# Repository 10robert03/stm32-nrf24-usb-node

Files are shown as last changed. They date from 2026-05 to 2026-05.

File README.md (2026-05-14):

# STM32-nRF24 Wireless USB Node

A compact 2-layer PCB featuring an **STM32C011** microcontroller and an **nRF24L01+** 2.4GHz wireless transceiver. This project was designed to bridge the gap between custom wireless sensor networks and USB-enabled host systems.

**⚠️ Project Status:** This project is currently in the **Hardware Prototype** stage. The PCB layout is complete, but the board has not yet been fully assembled or laboratory tested. Use with caution for production environments.

## Technical Highlights
- **Microcontroller:** STM32C011 (Arm Cortex-M0+), chosen for its efficiency and compact form factor.
- **Wireless Interface:** nRF24L01+ module connector, providing low-power 2.4GHz communication via SPI.
- **USB-UART Bridge:** Integrated **MCP2200** for seamless serial debugging and data acquisition.
- **Power Management:** Supports wide input voltage (5V - 36V) via **TSR 0.5-2433** DC/DC buck regulator.
  - Reverse polarity protection via Schottky diode.
  - Decoupled USB-C port (Data only) to prevent VBUS conflicts with host devices.

## Engineering Lessons & Design Choices

During the development of this board, several critical hardware engineering principles were implemented to ensure stability and signal integrity:

### 1. High-Frequency Signal Integrity
* **Series Termination:** Integrated series resistors on high-speed lines to dampen ringing and control rise/fall times. This minimizes electromagnetic interference (EMI) and prevents signal reflections.
* **Impedance Control:** Careful routing of USB D+/D- differential pairs to maintain signal quality for the MCP2200 bridge.

### 2. Clock & Timing Precision
* **Independent Oscillators:** Implemented separate external crystals for the STM32 (8 MHz) and MCP2200 (12 MHz). 
* **Parasitic Optimization:** Load capacitors were placed in immediate proximity to the crystals to minimize parasitic inductance and ensure a stable startup of the oscillation.

### 3. Power Integrity & Noise Suppression
* **Decoupling Strategy:** Strategic placement of ceramic decoupling capacitors (100nF) directly at the VCC pins of each IC to provide local energy storage and filter high-frequency switching noise.
* **RF-Sensitive Filtering:** Added LC-filtering stages at the output of the switching regulator to provide a "clean" 3.3V rail for the nRF24L01+, which is highly sensitive to power supply ripple.

### 4. Advanced PCB Layout Techniques
* **Tight Component Placement:** Mastered the challenge of placing high-pin-count components (USB-C, STM32, MCP2200) in a very confined space while maintaining minimum clearance for the Ground Plane (GND).
* **Thermal Management:** Solid Ground Fill on the bottom layer acts as a heat sink and provides a low-impedance return path for all signals.

##  Project Structure
- `/Screenshots`: High-resolution renders, schematic snips, and hardware photos.
- `stm32c_nrf.kicad_pcb`: The 2-layer board layout.
- `stm32c_nrf.kicad_sch`: The full electrical schematic.

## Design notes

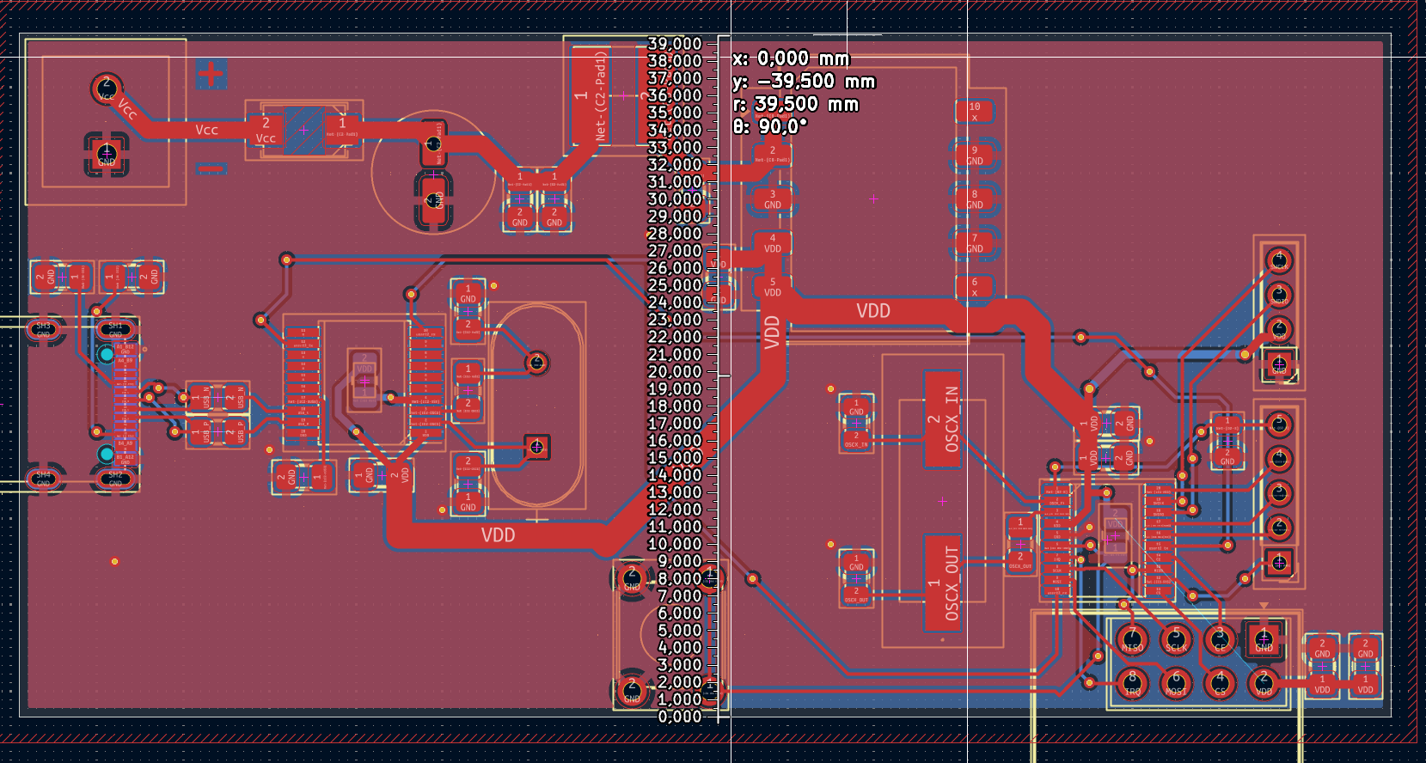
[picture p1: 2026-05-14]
Screenshots/pcb_y_axis_length.png

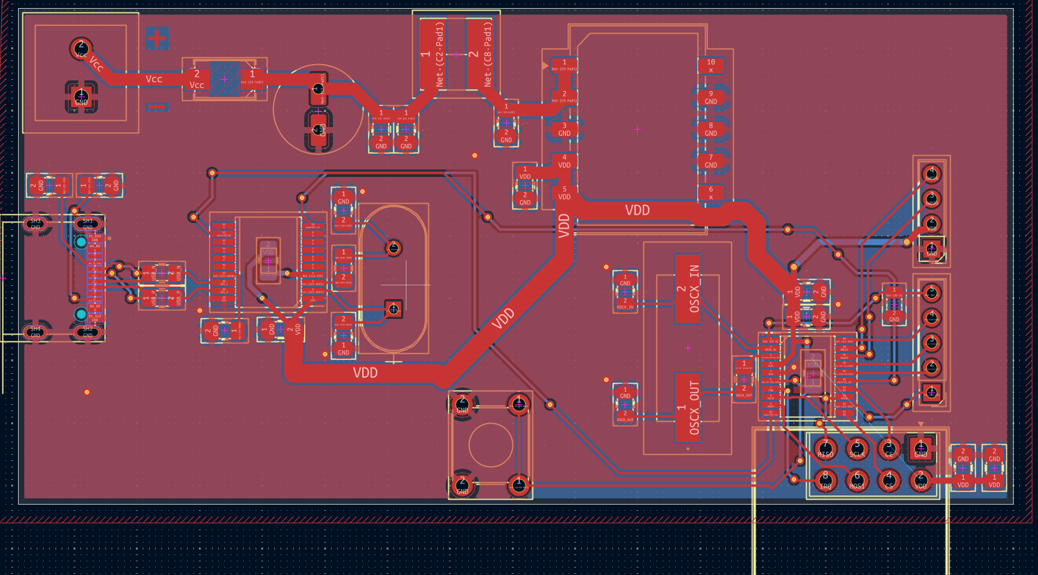
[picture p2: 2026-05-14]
Screenshots/PCB.png

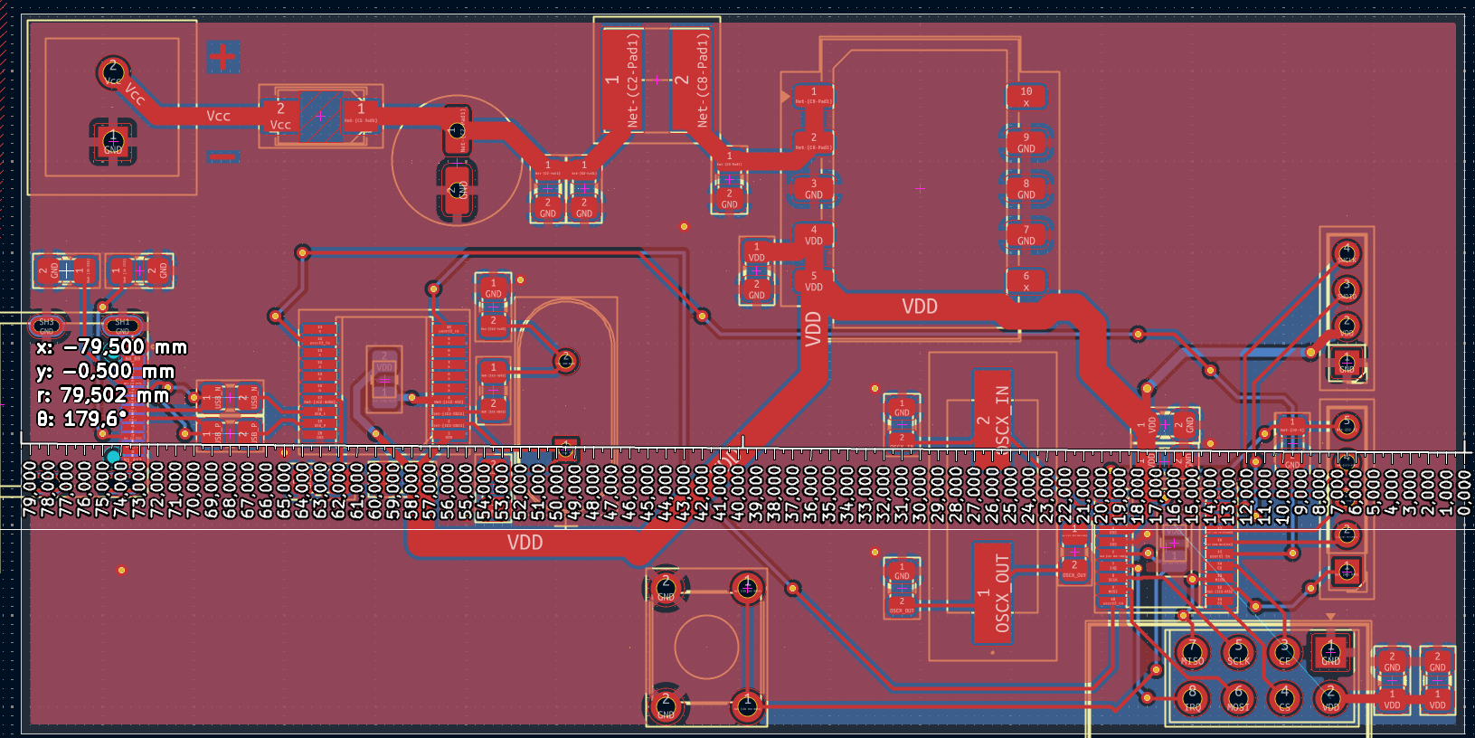
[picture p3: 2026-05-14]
Screenshots/pcb_x_axis_length.png

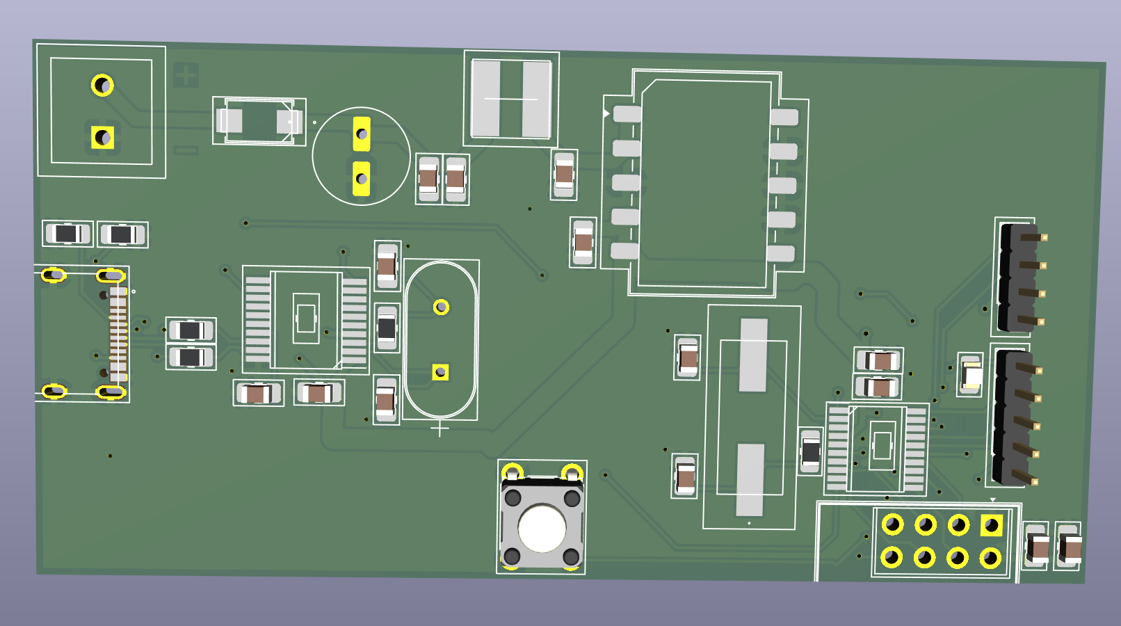
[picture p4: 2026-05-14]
Screenshots/3D_pcb_front.png

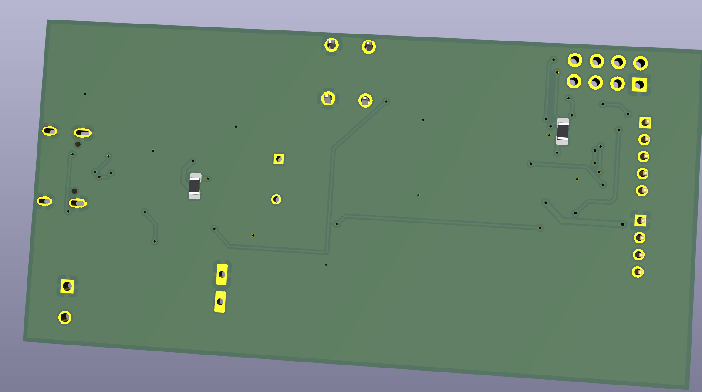
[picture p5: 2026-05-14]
Screenshots/3D_pcb_back.png

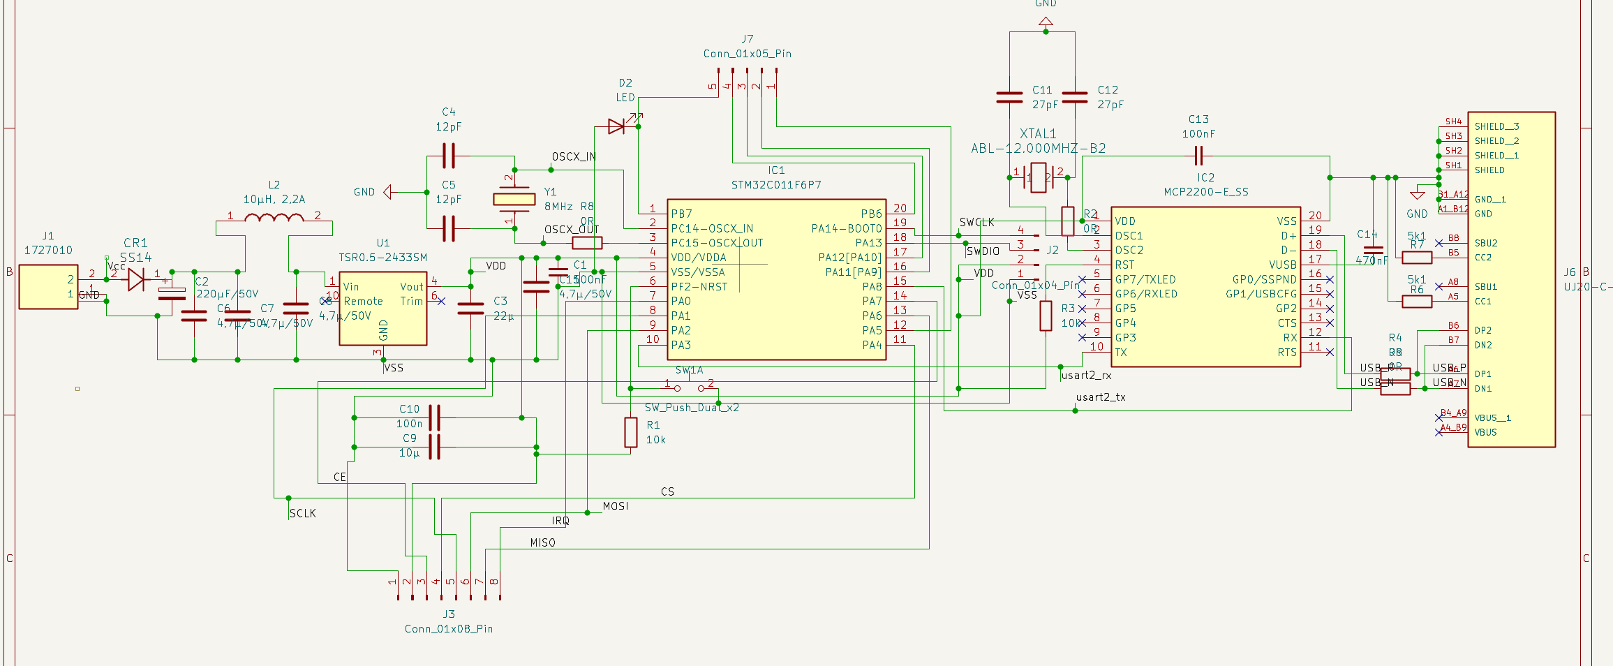
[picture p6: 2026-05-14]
Screenshots/circuit_diagram.png

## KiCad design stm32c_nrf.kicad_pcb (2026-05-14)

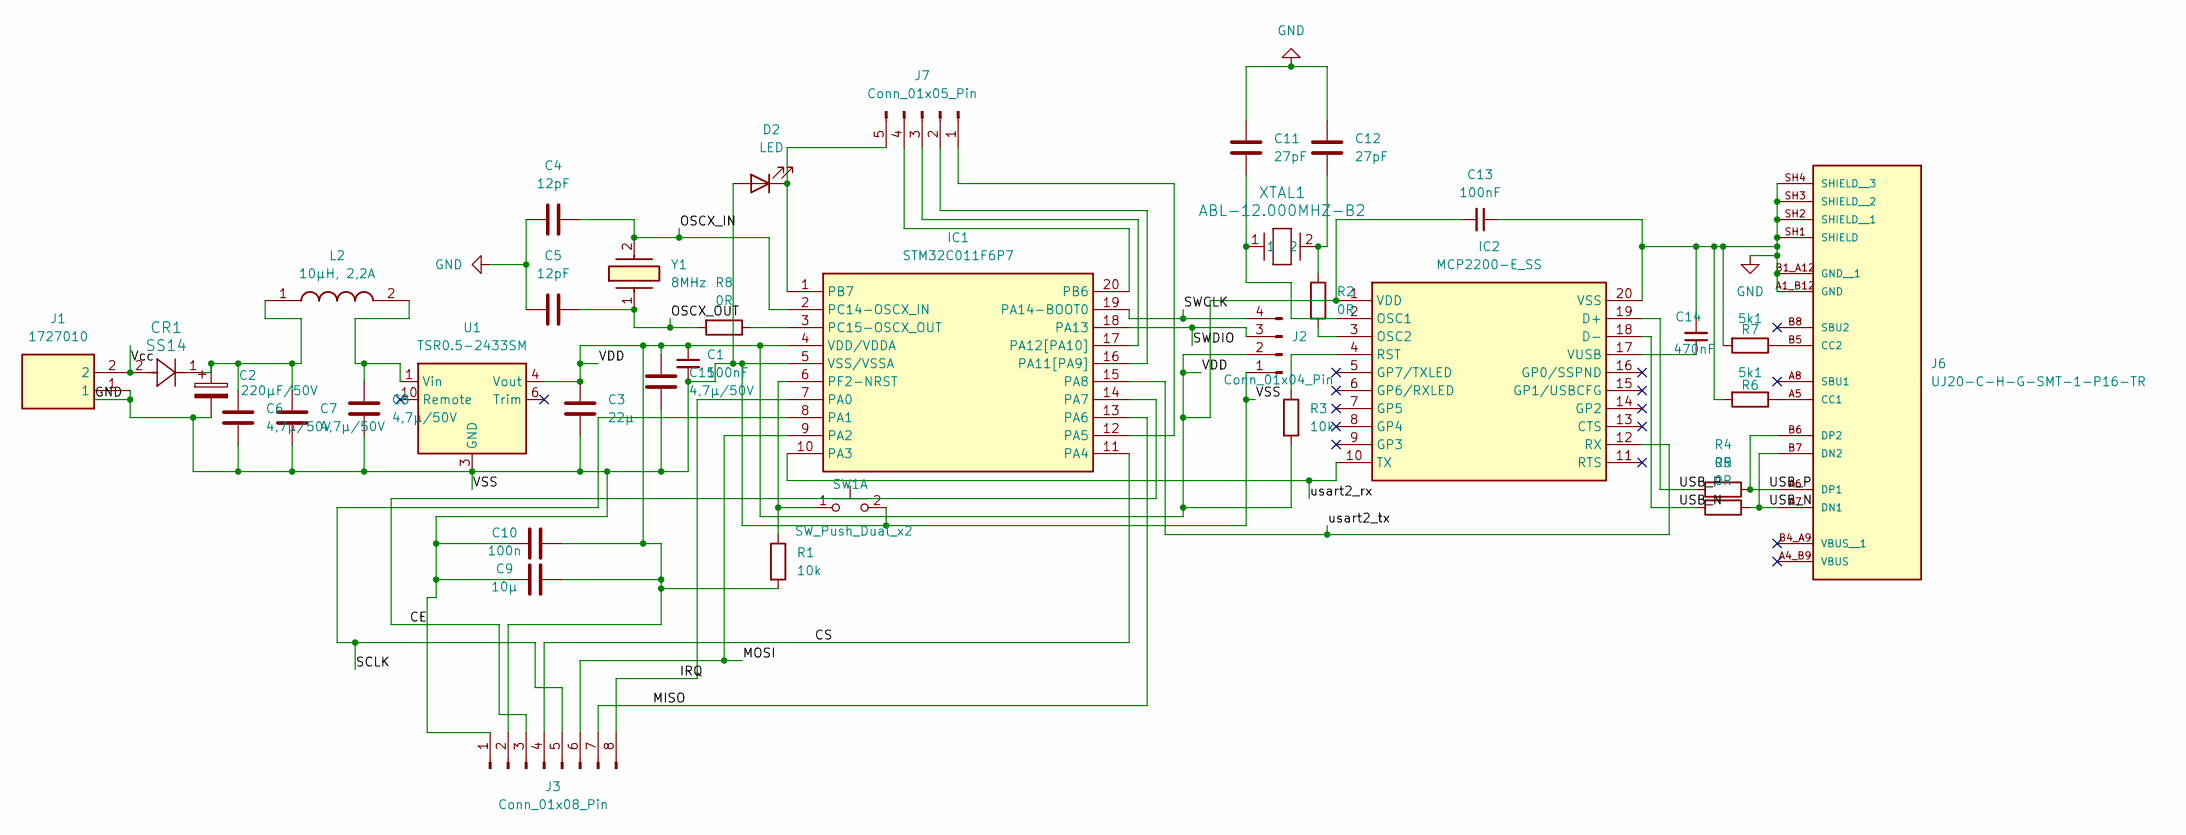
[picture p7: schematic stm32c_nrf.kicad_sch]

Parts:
C1, C13: 100nF; C_0805_2012Metric_Pad1.18x1.45mm_HandSolder
C2: 220µF/50V; Cap_Elec_6,2_3,3
C3: 22µ; C_0805_2012Metric_Pad1.18x1.45mm_HandSolder
C4, C5: 12pF; C_0805_2012Metric
C6, C7, C8, C15: 4,7µ/50V; C_0805_2012Metric_Pad1.18x1.45mm_HandSolder
C9: 10µ; C_0805_2012Metric_Pad1.18x1.45mm_HandSolder
C10: 100n; C_0805_2012Metric_Pad1.18x1.45mm_HandSolder
C11, C12: 27pF; C_0805_2012Metric_Pad1.18x1.45mm_HandSolder
C14: 470nF; C_0805_2012Metric_Pad1.18x1.45mm_HandSolder
CR1: SS14; CR_SMA_403AE_OSI
D2: LED; LED_0805_2012Metric
IC1: STM32C011F6P7; SOP65P640X120-20N; Manufacturer_Part_Number STM32C011F6P7; Mouser Part Number 511-STM32C011F6P7
IC2: MCP2200-E_SS; SOP65P780X200-20N; Mouser Part Number 494-MCP2200-E/SS
J1: 1727010; Mouser Part Number 651-1727010
J2: Conn_01x04_Pin; PinHeader_1x04_P2.00mm_Vertical
J3: Conn_01x08_Pin; nRF24L01_Breakout
J6: UJ20-C-H-G-SMT-1-P16-TR; SAMESKY_UJ20-C-H-G-SMT-1-P16-TR; PARTREV 1.0
J7: Conn_01x05_Pin; PinHeader_1x05_P2.00mm_Vertical
L2: 10µH, 2,2A; WE-PD2_5848_582055; Mouser Part Number 710-74477410
R1, R3: 10k; R_0805_2012Metric_Pad1.20x1.40mm_HandSolder
R2, R4, R5, R8: 0R; R_0805_2012Metric_Pad1.20x1.40mm_HandSolder
R6, R7: 5k1; R_0805_2012Metric_Pad1.20x1.40mm_HandSolder
SW1: SW_Push_Dual_x2; SW_TH_Tactile_Omron_B3F-100x
U1: TSR0.5-2433SM; Converter_DCDC_TRACO_TSR0.5-24xxSM_241xxSM_SMD
XTAL1: ABL-12.000MHZ-B2; XTAL_ABL_ABR
Y1: 8MHz; HC49SDLF800MHZ; Manufacturer_Part_Number HC49SDLF-8.00MHZ

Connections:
/CE: IC1.14 (PA7), J3.3
/CS: IC1.11 (PA4), J3.4
/IRQ: IC1.7 (PA0), J3.8
/MISO: IC1.13 (PA6), J3.7
/MOSI: IC1.9 (PA2), J3.6
/OSCX_IN: C4.2, IC1.2 (PC14-OSCX_IN), Y1.2
/OSCX_OUT: C5.2, R8.2, Y1.1
/SCLK: IC1.8 (PA1), J3.5
/SWCLK: IC1.19 (PA14-BOOT0), J2.4
/SWDIO: IC1.18 (PA13), J2.3
/USB_N: IC2.18 (D-), J6.A7 (DN1), J6.B7 (DN2), R5.1, R5.2
/USB_P: IC2.19 (D+), J6.A6 (DP1), J6.B6 (DP2), R4.1, R4.2
/VDD: C1.1, C3.1, C9.1, C10.1, C13.2, C15.1, IC1.4 (VDD/VDDA), IC2.1 (VDD), J2.2, J3.2, R1.2, R3.2, U1.4 (Vout), U1.5 (Vout)
/Vcc: CR1.2, J1.2
/usart2_rx: IC1.10 (PA3), IC2.10 (TX)
/usart2_tx: IC1.15 (PA8), IC2.12 (RX)
GND: C1.2, C2.2, C3.2, C4.1, C5.1, C6.2, C7.2, C8.2, C9.2, C10.2, C11.1, C12.1, C13.1, C14.2, C15.2, D2.2 (A), IC1.5 (VSS/VSSA), IC2.20 (VSS), J1.1, J2.1, J3.1, J6.A1_B12 (GND), J6.B1_A12 (GND__1), J6.SH1 (SHIELD), J6.SH2 (SHIELD__1), J6.SH3 (SHIELD__2), J6.SH4 (SHIELD__3), R6.2, R7.2, SW1.2 (D), U1.3 (GND), U1.7 (GND), U1.8 (GND), U1.9 (GND)
unnamed: C2.1, C6.1, C7.1, CR1.1, L2.1
unnamed: C8.1, L2.2, U1.1 (Vin), U1.2 (Vin)
unnamed: C12.2, R2.1, XTAL1.2
unnamed: D2.1 (K), IC1.1 (PB7), J7.5
unnamed: IC1.12 (PA5), J7.1
unnamed: IC1.16 (PA11[PA9]), J7.2
unnamed: IC1.17 (PA12[PA10]), J7.3
unnamed: IC1.20 (PB6), J7.4
unnamed: IC1.3 (PC15-OSCX_OUT), R8.1
unnamed: IC1.6 (PF2-NRST), R1.1, SW1.1 (C)
unnamed: C11.2, IC2.2 (OSC1), XTAL1.1
unnamed: IC2.3 (OSC2), R2.2
unnamed: IC2.4 (RST), R3.1
unnamed: C14.1, IC2.17 (VUSB)
unnamed: J6.A5 (CC1), R6.1
unnamed: J6.B5 (CC2), R7.1

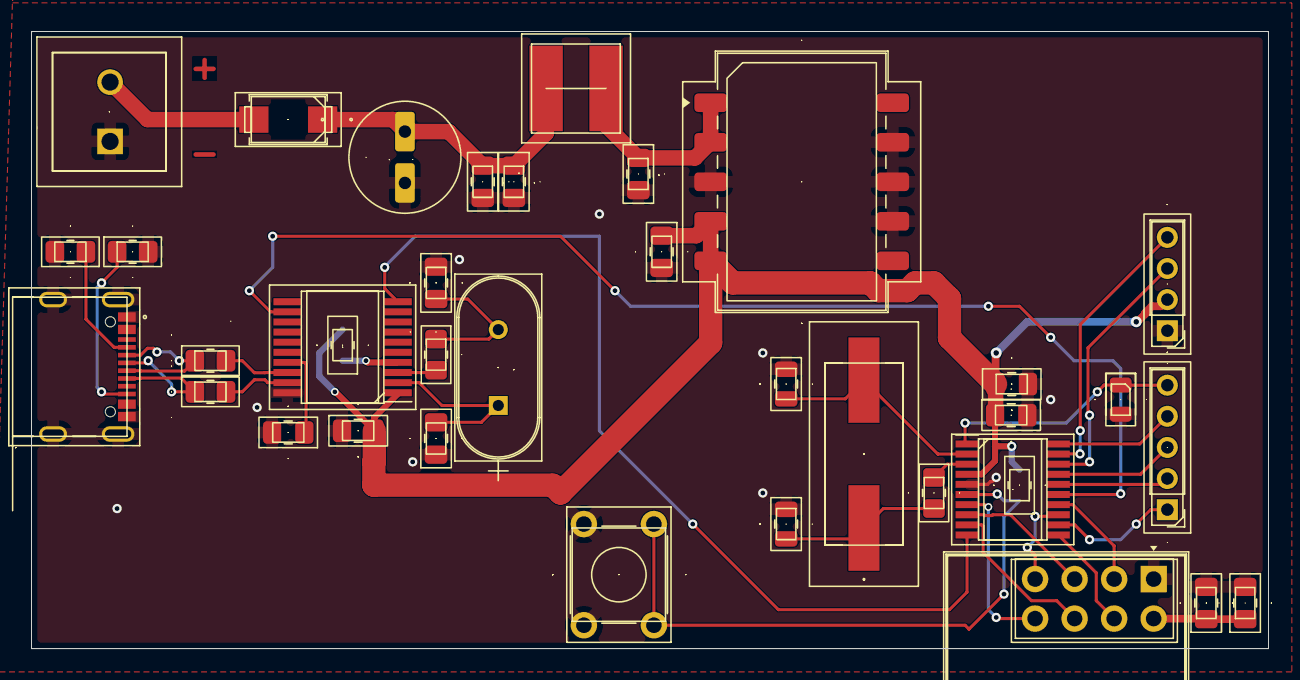
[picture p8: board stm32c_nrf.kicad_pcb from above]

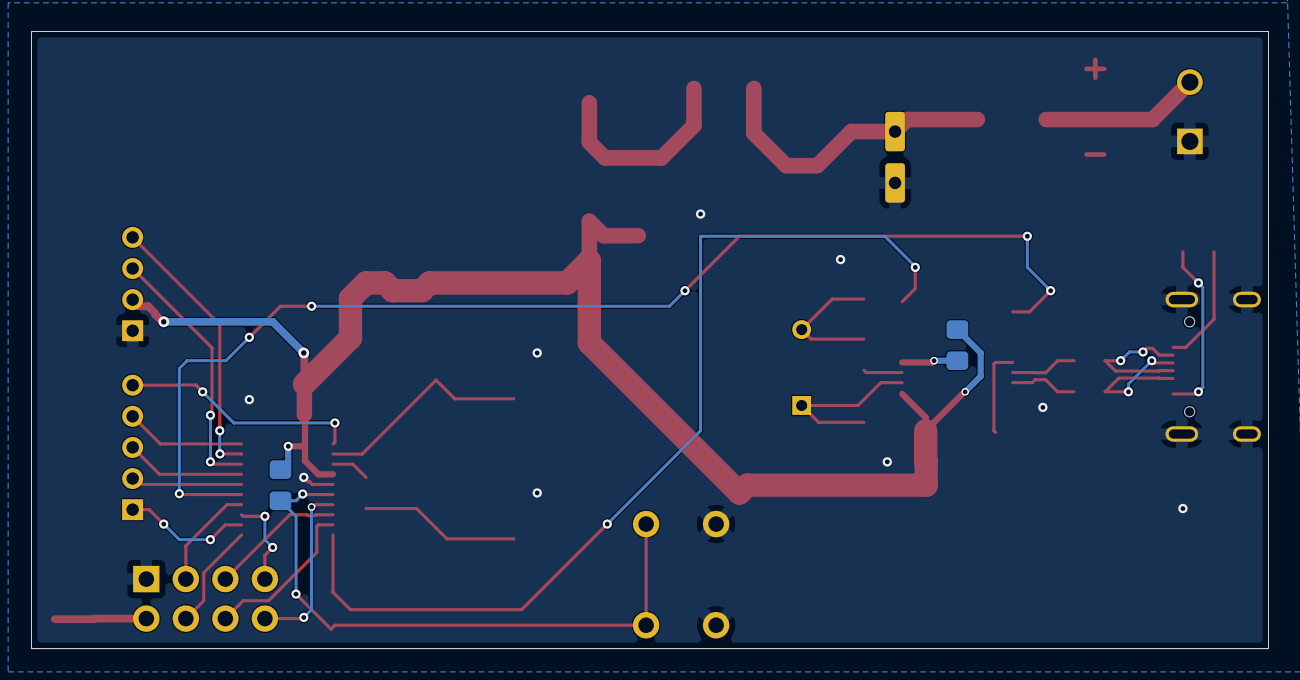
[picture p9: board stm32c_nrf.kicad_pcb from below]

Board: 2 copper layers, 79.5 x 39.7 mm, 37 parts (2 on the bottom side), 33 nets.
